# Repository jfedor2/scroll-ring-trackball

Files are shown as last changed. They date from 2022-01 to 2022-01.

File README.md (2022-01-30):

# DIY trackball with scroll ring

This repository contains design files and code that can be used to make a fully programmable four-button USB trackball with a scroll ring.

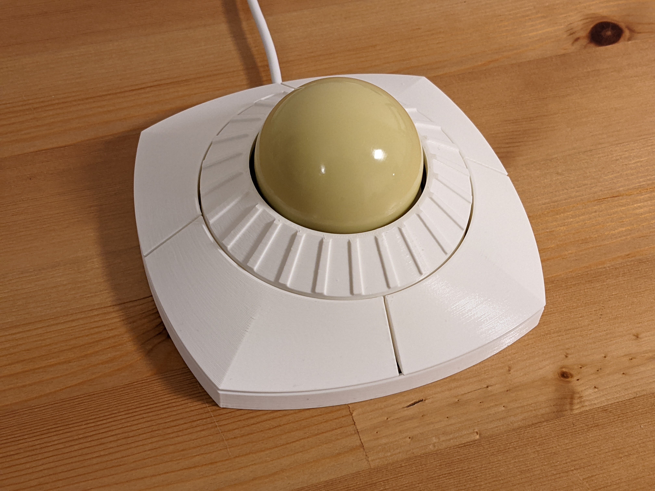
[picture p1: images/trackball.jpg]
Trackball photo


It uses the following components:

* 57.2mm billiard ball
* PMW3360 optical sensor
* [RP2040+PMW3360 PCB](https://github.com/jfedor2/rp2040-pmw3360)
* [button switch mount PCBs](https://github.com/jfedor2/mouse-switch-mount-pcb)
* [3D printed case](3d-models)
* Omron D2FC switches (or similar)
* 2x [SS49E Hall effect sensors](https://sps.honeywell.com/us/en/products/sensing-and-iot/sensors/magnetic-sensors/linear-and-angle-sensor-ics/ss39et-ss49e-ss59et-linear-sensor-ics) (TO-92 package)
* 72x 2x2mm neodymium cylinder magnets (axially magnetized)
* 60x78x10mm bearing (6812 ZZ)
* 2.5mm zirconium oxide (or silicon nitride) bearing balls
* M3x4 screws for mounting the main PCB and assembling the case
* M2x4 screws for mounting the buttons and the secondary PCBs
* USB cable (cut off the device end and solder the wires directly to the PCB)
* some hookup wire

The main PCB uses the RP2040 chip from Raspberry Pi. The firmware supports remapping of ball, button and ring functions using a configuration tool without the need to recompile the source code. All the configuration is stored on device, so the configuration tool is only needed to change the settings, not during normal use.

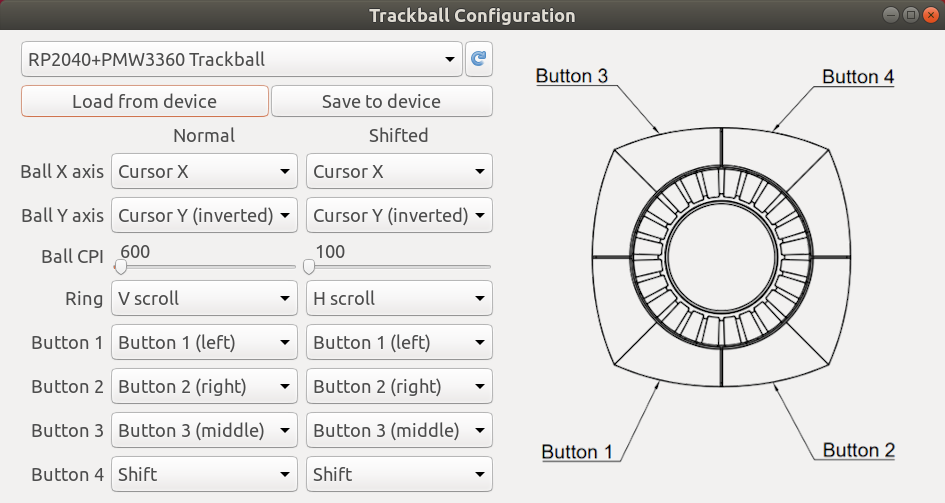
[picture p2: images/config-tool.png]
Configuration tool UI screenshot


So far I only tested the configuration tool on Linux, but it should in theory run on Windows and Mac as well. I will try to provide ready-to-use packages in the future.

The provided [UF2 file](firmware/trackball.uf2) can be used to flash the firmware onto the device. When first connected, a "RPI-RP2" drive will show up and you flash the chip by copying the UF2 file to that drive. If you want to flash it again, hold the BOOT button and press the RESET button on the board.

I printed the case parts with 0.2mm layer height. They don't need supports.

The bearing and the magnets are press-fit into the case, but depending on your particular printer you might want to use glue. The Hall effect sensors should be oriented "face-up" and will definitely need some glue to stay in place.

The magnets should be installed with alternating polarity (the outside-facing pole should be N-S-N-S... etc.).

The Hall sensors' + leads are connected to 3.3V. The rest of the pin numbers are defined at the top of [trackball.cc](firmware/src/trackball.cc).

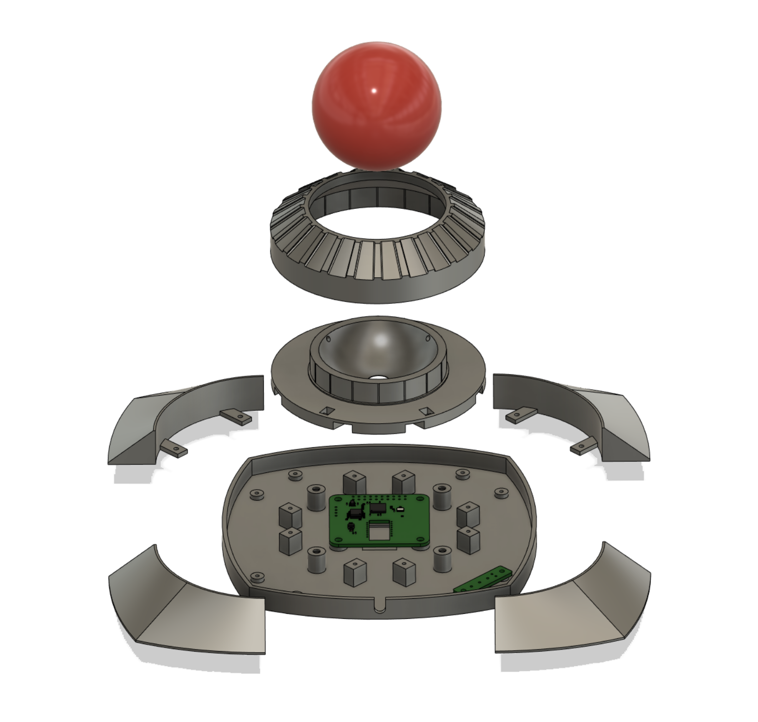
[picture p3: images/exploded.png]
Exploded view


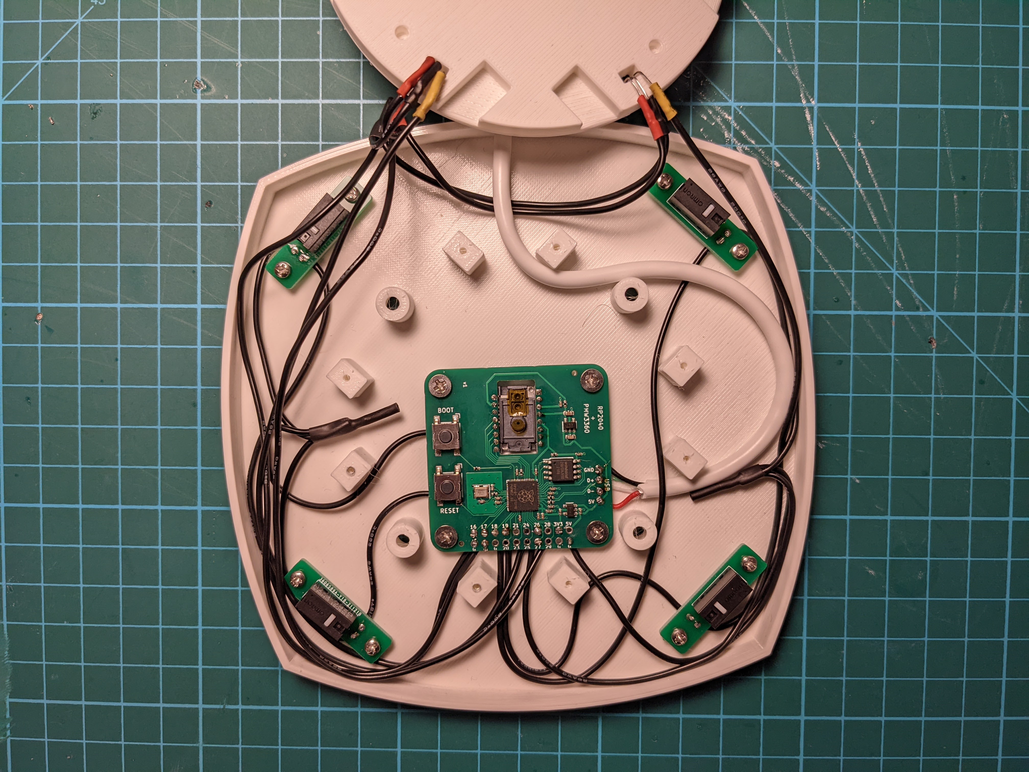
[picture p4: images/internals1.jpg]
Internals of the trackball


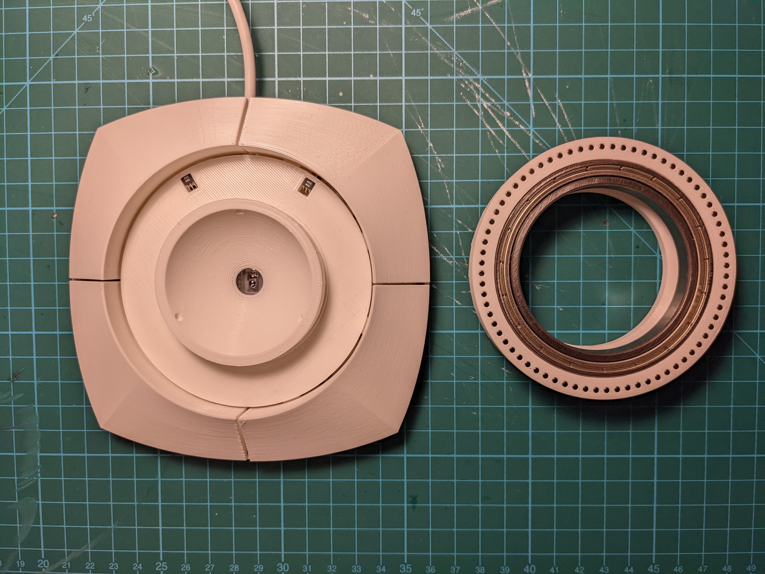
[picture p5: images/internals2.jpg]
Internals of the trackball


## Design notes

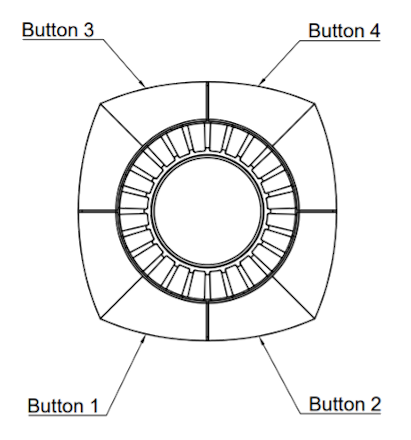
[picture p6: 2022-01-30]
config-tool/trackball.png

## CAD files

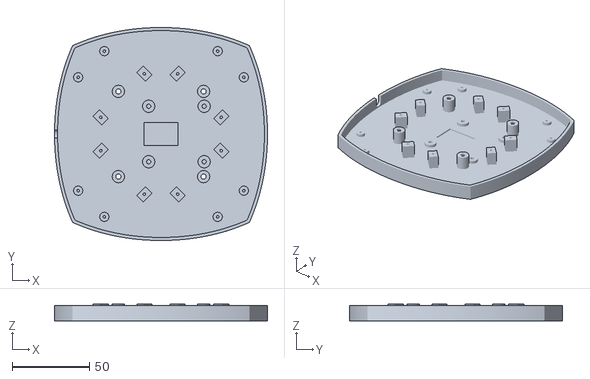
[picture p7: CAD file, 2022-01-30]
3d-models/Trackball14-Bottom.stl
138.2 x 138.2 x 11.0

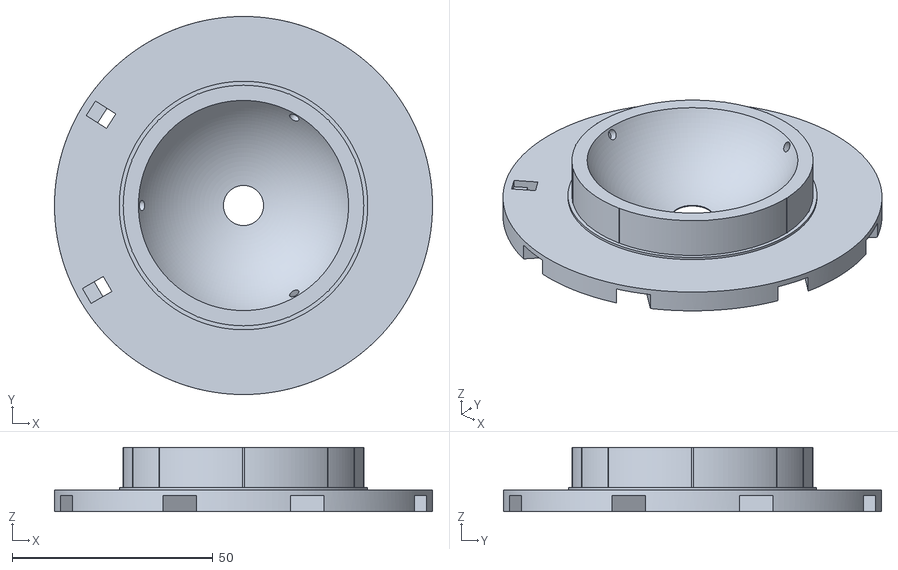
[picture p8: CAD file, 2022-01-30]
3d-models/Trackball14-Top.stl
94.2 x 94.2 x 16.0

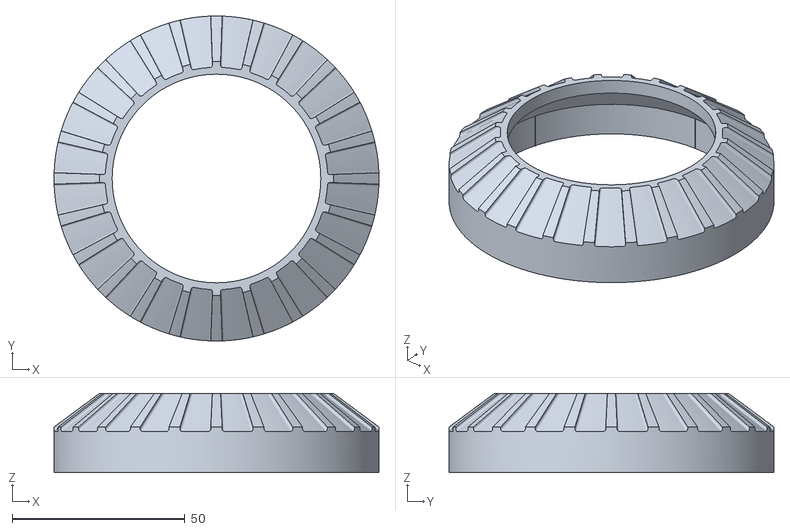
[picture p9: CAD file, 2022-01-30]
3d-models/Trackball14-Ring.stl
94.2 x 94.2 x 23.0

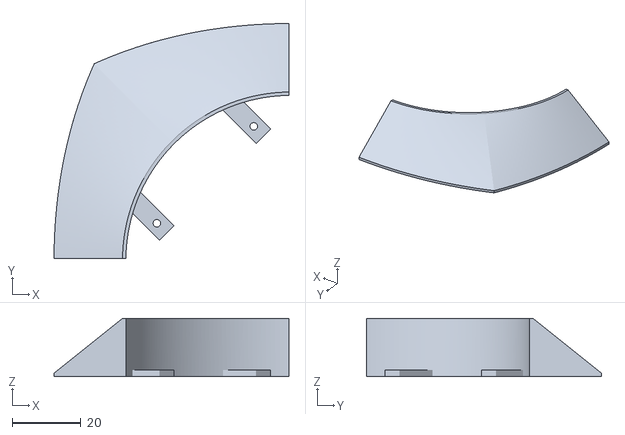
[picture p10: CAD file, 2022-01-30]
3d-models/Trackball14-Button.stl
68.6 x 68.6 x 17.0

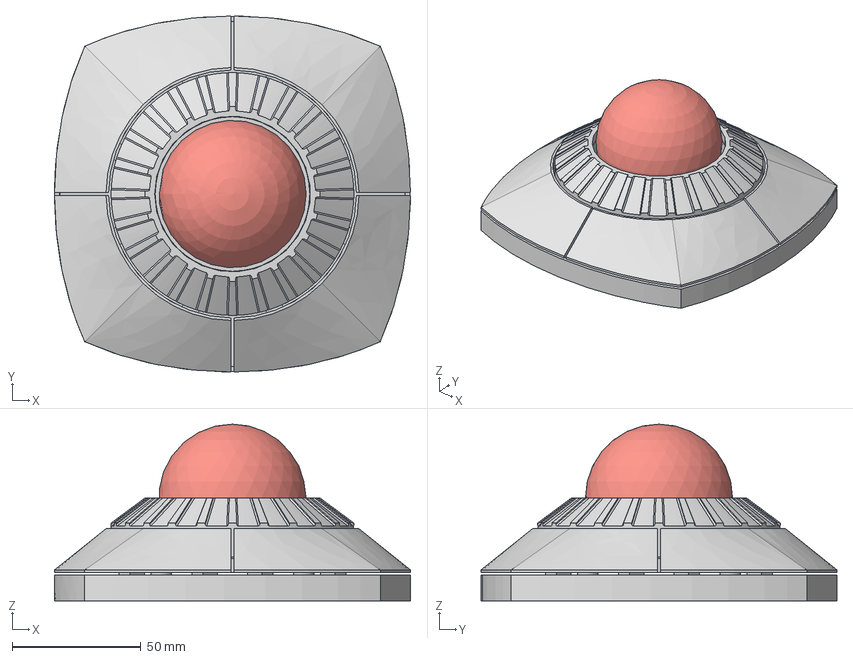
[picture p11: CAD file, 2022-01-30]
3d-models/Trackball14.step
138.2 x 138.2 x 68.6 mm

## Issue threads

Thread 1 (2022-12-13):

need a breakout pcb for the scroll ring encoders.

itsnoteasy, 2022-12-13:
there should be kicad files for a simple pcb that carries the vcc and gnd between both hall effect sensors, the pcb would have a hole to screw it to the top stl. the pcb would prevent the legs of the hall effect sensors from shorting together. the pcb would have headers for the 4 wires, 3.3v, gnd, and the two sensor pins.

also the button switch pcb should have a location for a through hole pullup resistor (to avoid smt assembly cost), and an extra header for 3.3v. It would be better if each button switch pcb had two headers for gnd and two for 3.3v. that is so that you can daisy chain a wire from one switch to the next, rather than having a large bundle of grounds tied together that could short something out if moved.

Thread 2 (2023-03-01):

suggested modifications to the 3d print

itsnoteasy, 2023-03-01:
I've built this and you've seen the image i linked on twitter. however there's a few issues,

one is that there's no way to move the trackball without clicking the buttons. this could be remedied by raising the outer wall to 1 1/2 times the existing height on the bottom stl. this requires the buttons acute edge to be truncated so that they do not hit the wall. i have filed down the buttons on my build so that i can lift it and it works.

another idea is to allow the use of the internals from the two ball trackball. this would allow high definition scrolling. this can be accomplished by rotating each of the 4 base standoffs 45 degrees, along with the matching holes in the ring stl. the room this makes would allow the second pmw3360 sensor to be placed between the screw holes of either button closest to the usb cable entry point. there would need to be a hole made in the ring stl to accept the lens.

These modifications will work fine with the existing hall sensor, as well as the two ball pcbs, leaving the assembly up to the user.

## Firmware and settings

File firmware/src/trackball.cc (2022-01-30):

/* 
 * The MIT License (MIT)
 *
 * Copyright (c) 2022 Jacek Fedorynski
 * Copyright (c) 2019 Ha Thach (tinyusb.org)
 *
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
 */

#include <stdio.h>
#include <stdlib.h>
#include <string.h>

#include <bsp/board.h>
#include <tusb.h>

#include <pico/bootrom.h>
#include <pico/stdlib.h>

#include <hardware/adc.h>
#include <hardware/flash.h>
#include <hardware/gpio.h>

#include "crc.h"
#include "pmw3360.h"

// These IDs are bogus. If you want to distribute any hardware using this,
// you will have to get real ones.
#define USB_VID 0xCAFE
#define USB_PID 0xBAFA

#define CONFIG_VERSION 1
#define CONFIG_SIZE 22

#define NBUTTONS 4
#define RESOLUTION_MULTIPLIER 120

#define PRESUMED_FLASH_SIZE 2097152
#define CONFIG_OFFSET_IN_FLASH (PRESUMED_FLASH_SIZE - FLASH_SECTOR_SIZE)
#define FLASH_CONFIG_IN_MEMORY (((uint8_t*) XIP_BASE) + CONFIG_OFFSET_IN_FLASH)

uint button_pins[NBUTTONS] = { 16, 19, 17, 18 };

#define SENSOR0_SPI spi0
#define SENSOR0_MISO 4
#define SENSOR0_MOSI 3
#define SENSOR0_SCK 2
#define SENSOR0_NCS 9

#define HALL_SENSOR1_PIN 26
#define HALL_SENSOR2_PIN 27
#define HALL_SENSOR1_INPUT 0
#define HALL_SENSOR2_INPUT 1

#define V_RESOLUTION_BITMASK (1 << 0)
#define H_RESOLUTION_BITMASK (1 << 2)

PMW3360 sensor = PMW3360(SENSOR0_SPI, SENSOR0_MISO, SENSOR0_MOSI, SENSOR0_SCK, SENSOR0_NCS);

tusb_desc_device_t const desc_device = {
    .bLength = sizeof(tusb_desc_device_t),
    .bDescriptorType = TUSB_DESC_DEVICE,
    .bcdUSB = 0x0200,
    .bDeviceClass = 0x00,
    .bDeviceSubClass = 0x00,
    .bDeviceProtocol = 0x00,
    .bMaxPacketSize0 = CFG_TUD_ENDPOINT0_SIZE,

    .idVendor = USB_VID,
    .idProduct = USB_PID,
    .bcdDevice = 0x0100,

    .iManufacturer = 0x01,
    .iProduct = 0x02,
    .iSerialNumber = 0x00,

    .bNumConfigurations = 0x01,
};

uint8_t const desc_hid_report[] = {
    0x05, 0x01,                   // Usage Page (Generic Desktop Ctrls)
    0x09, 0x02,                   // Usage (Mouse)
    0xA1, 0x01,                   // Collection (Application)
    0x05, 0x01,                   //   Usage Page (Generic Desktop Ctrls)
    0x09, 0x02,                   //   Usage (Mouse)
    0xA1, 0x02,                   //   Collection (Logical)
    0x85, 0x01,                   //     Report ID (1)
    0x09, 0x01,                   //     Usage (Pointer)
    0xA1, 0x00,                   //     Collection (Physical)
    0x05, 0x09,                   //       Usage Page (Button)
    0x19, 0x01,                   //       Usage Minimum (0x01)
    0x29, 0x08,                   //       Usage Maximum (0x08)
    0x95, 0x08,                   //       Report Count (8)
    0x75, 0x01,                   //       Report Size (1)
    0x25, 0x01,                   //       Logical Maximum (1)
    0x81, 0x02,                   //       Input (Data,Var,Abs,No Wrap,Linear,Preferred State,No Null Position)
    0x05, 0x01,                   //       Usage Page (Generic Desktop Ctrls)
    0x09, 0x30,                   //       Usage (X)
    0x09, 0x31,                   //       Usage (Y)
    0x95, 0x02,                   //       Report Count (2)
    0x75, 0x10,                   //       Report Size (16)
    0x16, 0x00, 0x80,             //       Logical Minimum (-32768)
    0x26, 0xFF, 0x7F,             //       Logical Maximum (32767)
    0x81, 0x06,                   //       Input (Data,Var,Rel,No Wrap,Linear,Preferred State,No Null Position)
    0xA1, 0x02,                   //       Collection (Logical)
    0x85, 0x02,                   //         Report ID (2)
    0x09, 0x48,                   //         Usage (Resolution Multiplier)
    0x95, 0x01,                   //         Report Count (1)
    0x75, 0x02,                   //         Report Size (2)
    0x15, 0x00,                   //         Logical Minimum (0)
    0x25, 0x01,                   //         Logical Maximum (1)
    0x35, 0x01,                   //         Physical Minimum (1)
    0x45, RESOLUTION_MULTIPLIER,  //         Physical Maximum (RESOLUTION_MULTIPLIER)
    0xB1, 0x02,                   //         Feature (Data,Var,Abs,No Wrap,Linear,Preferred State,No Null Position,Non-volatile)
    0x85, 0x01,                   //         Report ID (1)
    0x09, 0x38,                   //         Usage (Wheel)
    0x35, 0x00,                   //         Physical Minimum (0)
    0x45, 0x00,                   //         Physical Maximum (0)
    0x16, 0x00, 0x80,             //         Logical Minimum (-32768)
    0x26, 0xFF, 0x7F,             //         Logical Maximum (32767)
    0x75, 0x10,                   //         Report Size (16)
    0x81, 0x06,                   //         Input (Data,Var,Rel,No Wrap,Linear,Preferred State,No Null Position)
    0xC0,                         //       End Collection
    0xA1, 0x02,                   //       Collection (Logical)
    0x85, 0x02,                   //         Report ID (2)
    0x09, 0x48,                   //         Usage (Resolution Multiplier)
    0x75, 0x02,                   //         Report Size (2)
    0x15, 0x00,                   //         Logical Minimum (0)
    0x25, 0x01,                   //         Logical Maximum (1)
    0x35, 0x01,                   //         Physical Minimum (1)
    0x45, RESOLUTION_MULTIPLIER,  //         Physical Maximum (RESOLUTION_MULTIPLIER)
    0xB1, 0x02,                   //         Feature (Data,Var,Abs,No Wrap,Linear,Preferred State,No Null Position,Non-volatile)
    0x35, 0x00,                   //         Physical Minimum (0)
    0x45, 0x00,                   //         Physical Maximum (0)
    0x75, 0x04,                   //         Report Size (4)
    0xB1, 0x03,                   //         Feature (Const,Var,Abs,No Wrap,Linear,Preferred State,No Null Position,Non-volatile)
    0x85, 0x01,                   //         Report ID (1)
    0x05, 0x0C,                   //         Usage Page (Consumer)
    0x16, 0x00, 0x80,             //         Logical Minimum (-32768)
    0x26, 0xFF, 0x7F,             //         Logical Maximum (32767)
    0x75, 0x10,                   //         Report Size (16)
    0x0A, 0x38, 0x02,             //         Usage (AC Pan)
    0x81, 0x06,                   //         Input (Data,Var,Rel,No Wrap,Linear,Preferred State,No Null Position)
    0xC0,                         //       End Collection
    0xC0,                         //     End Collection
    0xC0,                         //   End Collection
    0x06, 0x00, 0xFF,             //   Usage Page (Vendor Defined 0xFF00)
    0x09, 0x20,                   //   Usage (0x20)
    0x85, 0x03,                   //   Report ID (3)
    0x75, 0x08,                   //   Report Size (8)
    0x95, CONFIG_SIZE,            //   Report Count (CONFIG_SIZE)
    0xB1, 0x02,                   //   Feature (Data,Var,Abs,No Wrap,Linear,Preferred State,No Null Position,Non-volatile)
    0xC0,                         // End Collection
};

#define CONFIG_TOTAL_LEN (TUD_CONFIG_DESC_LEN + TUD_HID_DESC_LEN)
#define EPNUM_HID 0x81

uint8_t const desc_configuration[] = {
    // Config number, interface count, string index, total length, attribute, power in mA
    TUD_CONFIG_DESCRIPTOR(1, 1, 0, CONFIG_TOTAL_LEN, 0, 100),

    // Interface number, string index, protocol, report descriptor len, EP In address, size & polling interval
    TUD_HID_DESCRIPTOR(0, 0, HID_ITF_PROTOCOL_NONE, sizeof(desc_hid_report), EPNUM_HID, CFG_TUD_HID_EP_BUFSIZE, 1)
};

char const* string_desc_arr[] = {
    (const char[]){ 0x09, 0x04 },  // 0: is supported language is English (0x0409)
    "RP2040+PMW3360",              // 1: Manufacturer
    "Trackball",                   // 2: Product
};

struct __attribute__((packed)) hid_report_t {
    uint8_t buttons;
    int16_t dx;
    int16_t dy;
    int16_t vwheel;
    int16_t hwheel;
};

hid_report_t report;

enum class ButtonFunction : int8_t {
    NO_FUNCTION = 0,
    BUTTON1 = 1,
    BUTTON2 = 2,
    BUTTON3 = 3,
    BUTTON4 = 4,
    BUTTON5 = 5,
    BUTTON6 = 6,
    BUTTON7 = 7,
    BUTTON8 = 8,
    CLICK_DRAG = 9,
    SHIFT = 10,
};

enum class BallFunction : int8_t {
    NO_FUNCTION = 0,
    CURSOR_X = 1,
    CURSOR_Y = 2,
    VERTICAL_SCROLL = 3,
    HORIZONTAL_SCROLL = 4,
    CURSOR_X_INVERTED = -1,
    CURSOR_Y_INVERTED = -2,
    VERTICAL_SCROLL_INVERTED = -3,
    HORIZONTAL_SCROLL_INVERTED = -4,
};

enum class RingFunction : int8_t {
    NO_FUNCTION = 0,
    VERTICAL_SCROLL = 1,
    HORIZONTAL_SCROLL = 2,
    VERTICAL_SCROLL_INVERTED = -1,
    HORIZONTAL_SCROLL_INVERTED = -2,
};

enum class ConfigCommand : int8_t {
    NO_COMMAND = 0,
    RESET_INTO_BOOTSEL = 1,
};

struct __attribute__((packed)) config_t {
    uint8_t version;
    ConfigCommand command;
    BallFunction ball_function[2];
    BallFunction ball_shifted_function[2];
    uint8_t ball_cpi;
    uint8_t ball_shifted_cpi;
    RingFunction ring_function;
    RingFunction ring_shifted_function;
    ButtonFunction button_function[NBUTTONS];
    ButtonFunction button_shifted_function[NBUTTONS];
    uint32_t crc32;
};

config_t config = {
    .version = CONFIG_VERSION,
    .command = ConfigCommand::NO_COMMAND,
    .ball_function = { BallFunction::CURSOR_X, BallFunction::CURSOR_Y_INVERTED },
    .ball_shifted_function = { BallFunction::CURSOR_X, BallFunction::CURSOR_Y_INVERTED },
    .ball_cpi = 600 / 100,
    .ball_shifted_cpi = 100 / 100,
    .ring_function = RingFunction::VERTICAL_SCROLL,
    .ring_shifted_function = RingFunction::HORIZONTAL_SCROLL,
    .button_function = {
        ButtonFunction::BUTTON1,
        ButtonFunction::BUTTON2,
        ButtonFunction::BUTTON3,
        ButtonFunction::SHIFT,
    },
    .button_shifted_function = {
        ButtonFunction::BUTTON1,
        ButtonFunction::BUTTON2,
        ButtonFunction::BUTTON3,
        ButtonFunction::SHIFT,
    },
    .crc32 = 0,
};

uint8_t resolution_multiplier = 0;

// 0 = sensor X, 1 = sensor Y, 2 = ring
int accumulated_scroll[3] = { 0 };
uint64_t last_scroll_timestamp[3] = { 0 };

uint32_t prev_pin_state = 0xffffffff;
bool click_drag = false;
uint8_t current_cpi = 0;

int16_t handle_scroll(int axis, int16_t movement, uint8_t multiplier_mask) {
    int16_t ret = 0;
    if (resolution_multiplier & multiplier_mask) {
        ret = movement;
    } else {
        if (movement != 0) {
            last_scroll_timestamp[axis] = time_us_64();
            accumulated_scroll[axis] += movement;
            int ticks = accumulated_scroll[axis] / RESOLUTION_MULTIPLIER;
            accumulated_scroll[axis] -= ticks * RESOLUTION_MULTIPLIER;
            ret = ticks;
        } else {
            if ((accumulated_scroll[axis] != 0) &&
                (time_us_64() - last_scroll_timestamp[axis] > 1000000)) {
                accumulated_scroll[axis] = 0;
            }
        }
    }
    return ret;
}

int encoder_rotation = 0;
int prev_state1 = 0;

void encoder_task(void) {
    adc_select_input(HALL_SENSOR1_INPUT);
    uint16_t val1 = adc_read();
    adc_select_input(HALL_SENSOR2_INPUT);
    uint16_t val2 = adc_read();

    int state1 = prev_state1;
    if (val1 > 2670) {
        state1 = 1;
    }
    if (val1 < 1602) {
        state1 = -1;
    }

    int state2 = 0;
    if (val2 > 2048) {
        state2 = 1;
    }
    if (val2 < 2048) {
        state2 = -1;
    }

    if (prev_state1 != state1) {
        if (state1 == state2) {
            encoder_rotation--;
        }
        if (state1 == -state2) {
            encoder_rotation++;
        }
    }

    prev_state1 = state1;
}

void hid_task() {
    if (!tud_hid_ready()) {
        return;
    }

    memset(&report, 0, sizeof(report));

    uint32_t pin_state = gpio_get_all();

    bool shifted = false;

    // first pass to determine if we're in shifted state
    for (int i = 0; i < NBUTTONS; i++) {
        if (config.button_function[i] == ButtonFunction::SHIFT &&
            !(pin_state & (1 << button_pins[i]))) {
            shifted = true;
        }
    }

    // set CPI if not already correct
    uint8_t wanted_cpi = shifted ? config.ball_shifted_cpi : config.ball_cpi;
    if (current_cpi != wanted_cpi && wanted_cpi >= 1 && wanted_cpi <= 120) {
        sensor.set_cpi(wanted_cpi * 100);
        current_cpi = wanted_cpi;
    }

    for (int i = 0; i < NBUTTONS; i++) {
        ButtonFunction button_function =
            shifted ? config.button_shifted_function[i] : config.button_function[i];
        if (config.button_function[i] == ButtonFunction::SHIFT) {
            button_function = ButtonFunction::NO_FUNCTION;
        }
        switch (button_function) {
            case ButtonFunction::NO_FUNCTION:
            case ButtonFunction::SHIFT:
                break;
            case ButtonFunction::BUTTON1:
            case ButtonFunction::BUTTON2:
            case ButtonFunction::BUTTON3:
            case ButtonFunction::BUTTON4:
            case ButtonFunction::BUTTON5:
            case ButtonFunction::BUTTON6:
            case ButtonFunction::BUTTON7:
            case ButtonFunction::BUTTON8: {
                int button = static_cast<int>(button_function) - 1;
                if (!(pin_state & (1 << button_pins[i]))) {
                    report.buttons |= 1 << button;
                }
                break;
            }
            case ButtonFunction::CLICK_DRAG:
                if ((prev_pin_state & (1 << button_pins[i])) &&
                    !(pin_state & (1 << button_pins[i]))) {
                    click_drag = !click_drag;
                }
                break;
        }
    }

    if (click_drag) {
        report.buttons |= 1 << 0;
    }

    prev_pin_state = pin_state;

    sensor.update();
    for (int axis = 0; axis < 2; axis++) {
        int16_t movement = sensor.movement[axis];
        BallFunction ball_function =
            shifted ? config.ball_shifted_function[axis] : config.ball_function[axis];
        if (static_cast<int>(ball_function) < 0) {
            movement *= -1;
        }
        switch (ball_function) {
            case BallFunction::NO_FUNCTION:
                break;
            case BallFunction::CURSOR_X:
            case BallFunction::CURSOR_X_INVERTED:
                report.dx += movement;
                break;
            case BallFunction::CURSOR_Y:
            case BallFunction::CURSOR_Y_INVERTED:
                report.dy += movement;
                break;
            case BallFunction::VERTICAL_SCROLL:
            case BallFunction::VERTICAL_SCROLL_INVERTED:
                report.vwheel += handle_scroll(axis, movement, V_RESOLUTION_BITMASK);
                break;
            case BallFunction::HORIZONTAL_SCROLL:
            case BallFunction::HORIZONTAL_SCROLL_INVERTED:
                report.hwheel += handle_scroll(axis, movement, H_RESOLUTION_BITMASK);
                break;
        }
    }

    int16_t ring_movement = encoder_rotation * RESOLUTION_MULTIPLIER;
    encoder_rotation = 0;
    RingFunction ring_function =
        shifted ? config.ring_shifted_function : config.ring_function;
    if (static_cast<int>(ring_function) < 0) {
        ring_movement *= -1;
    }
    switch (ring_function) {
        case RingFunction::NO_FUNCTION:
            break;
        case RingFunction::VERTICAL_SCROLL:
        case RingFunction::VERTICAL_SCROLL_INVERTED:
            report.vwheel += handle_scroll(2, ring_movement, V_RESOLUTION_BITMASK);
            break;
        case RingFunction::HORIZONTAL_SCROLL:
        case RingFunction::HORIZONTAL_SCROLL_INVERTED:
            report.hwheel += handle_scroll(2, ring_movement, H_RESOLUTION_BITMASK);
            break;
    }

    // uncomment to have pressing all four buttons reset into BOOTSEL
    // (convenient during development)
    // if (!(pin_state & (1 << button_pins[0]) ||
    //       pin_state & (1 << button_pins[1]) ||
    //       pin_state & (1 << button_pins[2]) ||
    //       pin_state & (1 << button_pins[3]))) {
    //     reset_usb_boot(0, 0);
    // }

    tud_hid_report(1, &report, sizeof(report));
}

void pin_init(uint pin) {
    gpio_init(pin);
    gpio_set_dir(pin, GPIO_IN);
    gpio_pull_up(pin);
}

void pins_init() {
    adc_init();
    adc_gpio_init(HALL_SENSOR1_PIN);
    adc_gpio_init(HALL_SENSOR2_PIN);
    for (int i = 0; i < NBUTTONS; i++) {
        pin_init(button_pins[i]);
    }
}

void sensor_init() {
    sensor.init();
}

void run_config_command() {
    // we probably shouldn't do this for config read from flash
    // or let's just not write any non-null command to flash
    if (config.command == ConfigCommand::RESET_INTO_BOOTSEL) {
        reset_usb_boot(0, 0);
    }
}

bool checksum_ok(const uint8_t* buffer) {
    return crc32(buffer, CONFIG_SIZE - 4) == ((config_t*) buffer)->crc32;
}

bool version_ok(const uint8_t* buffer) {
    return ((config_t*) buffer)->version == CONFIG_VERSION;
}

void load_config() {
    if (checksum_ok(FLASH_CONFIG_IN_MEMORY) && version_ok(FLASH_CONFIG_IN_MEMORY)) {
        memcpy(&config, FLASH_CONFIG_IN_MEMORY, CONFIG_SIZE);
    }
}

void persist_config() {
    uint8_t buffer[FLASH_PAGE_SIZE];
    memset(buffer, 0, sizeof(buffer));
    memcpy(buffer, &config, CONFIG_SIZE);
    uint32_t ints = save_and_disable_interrupts();
    flash_range_erase(CONFIG_OFFSET_IN_FLASH, FLASH_SECTOR_SIZE);
    flash_range_program(CONFIG_OFFSET_IN_FLASH, buffer, FLASH_PAGE_SIZE);
    restore_interrupts(ints);
}

int main() {
    stdio_init_all();
    board_init();
    load_config();
    pins_init();
    sensor_init();
    tusb_init();

    while (true) {
        tud_task();  // tinyusb device task
        encoder_task();
        hid_task();
    }

    return 0;
}

// Invoked when device is mounted
void tud_mount_cb() {
    // reset hi-res scroll for when we reboot from Windows into Linux
    resolution_multiplier = 0;
}

// Invoked when received GET DEVICE DESCRIPTOR
// Application return pointer to descriptor
uint8_t const* tud_descriptor_device_cb() {
    return (uint8_t const*) &desc_device;
}

// Invoked when received GET HID REPORT DESCRIPTOR
// Application return pointer to descriptor
// Descriptor contents must exist long enough for transfer to complete
uint8_t const* tud_hid_descriptor_report_cb(uint8_t itf) {
    return desc_hid_report;
}

// Invoked when received GET_REPORT control request
// Application must fill buffer report's content and return its length.
// Return zero will cause the stack to STALL request
uint16_t tud_hid_get_report_cb(uint8_t itf, uint8_t report_id, hid_report_type_t report_type, uint8_t* buffer, uint16_t reqlen) {
    if (report_id == 2 && reqlen >= 1) {
        memcpy(buffer, &resolution_multiplier, 1);
        return 1;
    }
    if (report_id == 3 && reqlen >= CONFIG_SIZE) {
        config.crc32 = crc32((uint8_t*) &config, CONFIG_SIZE - 4);
        memcpy(buffer, &config, CONFIG_SIZE);
        return CONFIG_SIZE;
    }

    return 0;
}

// Invoked when received SET_REPORT control request or
// received data on OUT endpoint ( Report ID = 0, Type = 0 )
void tud_hid_set_report_cb(uint8_t itf, uint8_t report_id, hid_report_type_t report_type, uint8_t const* buffer, uint16_t bufsize) {
    if (report_id == 2 && bufsize >= 1) {
        memcpy(&resolution_multiplier, buffer, 1);
    }
    if (report_id == 3 && bufsize >= CONFIG_SIZE) {
        if (checksum_ok(buffer) && version_ok(buffer)) {
            memcpy(&config, buffer, CONFIG_SIZE);
            run_config_command();
            persist_config();
        }
    }
}

// Invoked when received GET CONFIGURATION DESCRIPTOR
// Application return pointer to descriptor
// Descriptor contents must exist long enough for transfer to complete
uint8_t const* tud_descriptor_configuration_cb(uint8_t index) {
    return desc_configuration;
}

static uint16_t _desc_str[32];

// Invoked when received GET STRING DESCRIPTOR request
// Application return pointer to descriptor, whose contents must exist long enough for transfer to complete
uint16_t const* tud_descriptor_string_cb(uint8_t index, uint16_t langid) {
    uint8_t chr_count;

    if (index == 0) {
        memcpy(&_desc_str[1], string_desc_arr[0], 2);
        chr_count = 1;
    } else {
        // Note: the 0xEE index string is a Microsoft OS 1.0 Descriptors.
        // https://docs.microsoft.com/en-us/windows-hardware/drivers/usbcon/microsoft-defined-usb-descriptors

        if (!(index < sizeof(string_desc_arr) / sizeof(string_desc_arr[0])))
            return NULL;

        const char* str = string_desc_arr[index];

        // Cap at max char
        chr_count = strlen(str);
        if (chr_count > 31)
            chr_count = 31;

        // Convert ASCII string into UTF-16
        for (uint8_t i = 0; i < chr_count; i++) {
            _desc_str[1 + i] = str[i];
        }
    }

    // first byte is length (including header), second byte is string type
    _desc_str[0] = (TUSB_DESC_STRING << 8) | (2 * chr_count + 2);

    return _desc_str;
}
